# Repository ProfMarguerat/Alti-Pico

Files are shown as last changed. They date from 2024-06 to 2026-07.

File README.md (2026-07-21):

# Alti Pico

Programme pour altimètre à partir d'un Raspberry Pico.  
Le schéma est identique que vous utilisiez un BMP280 ou un BME280 (seul la prise d'hygrométrie diffère pour le bme).  
Il y a un code pour le BMP et un autre pour le BME.  
Il y a également une librairie pour chaque composant.  
Il est possible de télécharger les librairies directement avec Thonny.  

Pour construire cet altimètre, il faut :
- un raspberry Pico
- un lipo Shim pour Pico
- une petite batterie lipo 
- un ecran oled 0,96"
- un capteur BME280
- un buzzer
- un bouton poussoir
- une plaque de prototypage pour braser les différents éléments.

Dans la partie Support_3D, vous retrouverez les fichiers pour fabriquer un support allant dans un tube de 40mm de diamètre interne.

Il y a une version avec la commande d'un servo moteur pour ouvrir une trape juste après l'apogée.

## Dossier du Pico :



## Schéma de câblage :

alti_pico_bb

## Construction :

IMG_0586_resultat
IMG_0587_resultat
IMG_0588_resultat
IMG_0589_resultat
IMG_0591_resultat
IMG_0594_resultat




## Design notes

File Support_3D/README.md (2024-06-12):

Support pour ogive de 40mm de diamètre interne.  

https://github.com/ProfMarguerat/Alti-Pico/assets/171016883/6b52e9af-b229-4efd-b042-83c573405da9

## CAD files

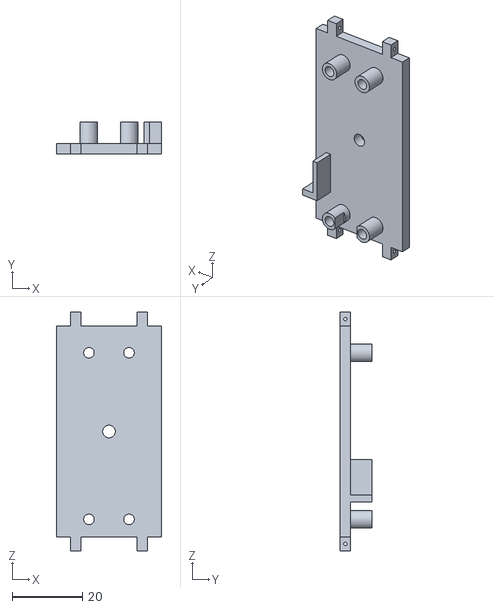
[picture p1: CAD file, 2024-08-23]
Support_3D/Plaque-Support_pico-40_III.STL
30.0 x 9.00 x 68.0

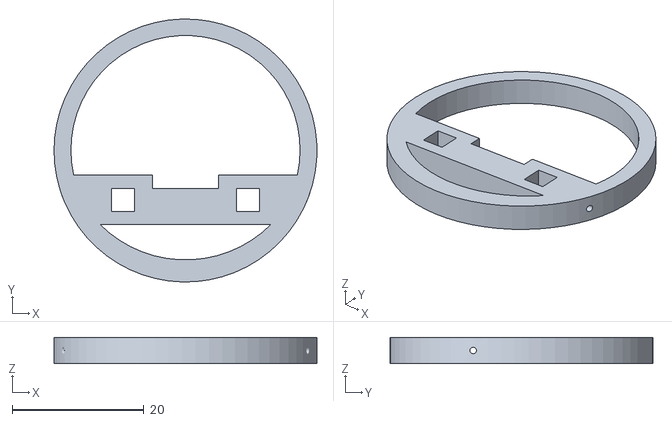
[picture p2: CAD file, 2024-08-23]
Support_3D/Bout_support_pico-40.STL
40.0 x 40.0 x 4.00

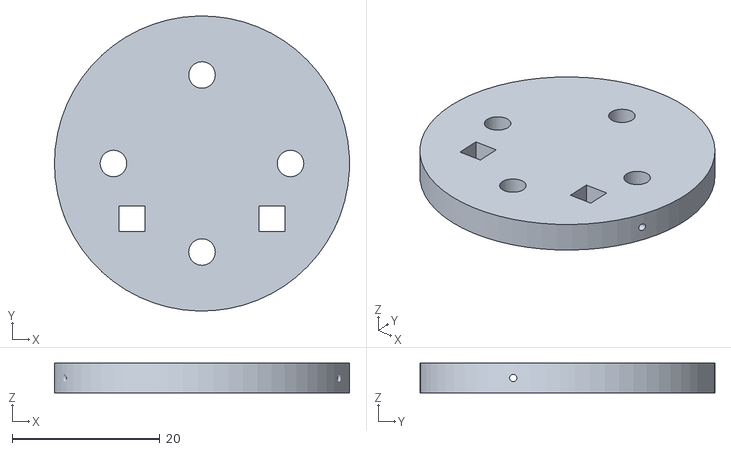
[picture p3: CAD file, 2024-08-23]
Support_3D/Bout-ogive_support_pico-40.STL
40.0 x 40.0 x 4.00

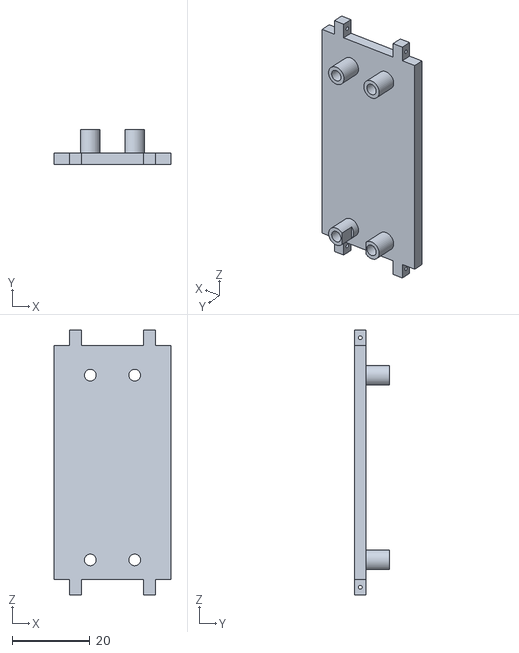
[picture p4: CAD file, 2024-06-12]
Support_3D/Plaque-Support_pico-40_II.STL
30.0 x 9.00 x 68.0

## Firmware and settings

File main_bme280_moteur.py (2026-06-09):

# Programme pour altimètre Pico avec un BME280


# import the required libraries
import bme280
from machine import Pin, I2C, PWM, Timer
import utime, _thread, math
from ssd1306 import SSD1306_I2C
from random import randint
from time import ticks_ms, sleep

led = Pin("LED", Pin.OUT)
led.on()

#Initialisation moteur porte :

servo = machine.PWM(machine.Pin(15))  # signal PWM à la broche GP 15
servo.freq(50) # réglage de la fréquence

servo.duty_u16(4000)    # rapport cyclique 3500/65535
utime.sleep(.5)          # temps d'arrêt


print("creation d'un nouveau fichier")
r = randint (0,1000000000)
fichier =("BME280_Tableau")+(str(r))+(".csv")
print(fichier)#juste pour verif le nom du fichier en debug
tableau_valeur = open(fichier,'w')
tableau_valeur.write('Temperature ; Pression ; Altitude ; Temps')
tableau_valeur.close()

led.off()

sea_level_pressure = 1013.25
cpt=0
boutton = Pin(10, mode=Pin.IN, pull=Pin.PULL_UP)
buzzer = PWM(Pin(16))
buzzer.freq(400)
buzzer.duty_u16(1000)
utime.sleep(0.1)
buzzer.duty_u16(0)


# Caliberation error in pressure
# use it according to your situation
# it helps in calibrating altitude .It is optional, else put ERROR = 0 
ERROR = -3 # hPa 

# declare pins for I2C communication
sclPin = Pin(9) # serial clock pin
sdaPin = Pin(8) # serial data pin

# Initiate I2C 
i2c = I2C(0,              # positional argument - I2C id
                 scl = sclPin,   # named argument - serial clock pin
                 sda = sdaPin,   # named argument - serial data pin
                 freq = 1000000) # named argument - i2c frequency

WIDTH =128 
HEIGHT= 32
oled = SSD1306_I2C(WIDTH,HEIGHT,i2c)
import framebuf

TH = bytearray(b'\x00\x00\x00\x00\x00\x00\x00\x00\x10\x00\x00\x00\x10\x00\x00\x00\x00\x00\x00\x00\x00\x00\x00\x00\x00\x00\x00\x00\x10\x00\x00\x00\x00\x01\x00\x00\x00\x01\x00\x00\x00\x00\x00\x00\x00\x00\x00\x00\x00\x00\x00\x00\x00\x00\x00\x00\x00\x00\x08\x00\x04\x00\x08\x00\x00\x00\x00\x00\x00\x00\x00\x00\x00\x00\x00\x00\x00\x00\x00\x00\x00\x00\x08\x10\x00\x00\x08\x10\x00\x00\x00 \x00\x00\x00 \x00\x00\x00\x02\x00\x00\x00\x02\x00\x01\x00\x00\x00\t\x00\x00B\x02\x0f\xe0@\x00\x00\x00\x80\x00\x7f\xf8\x00\x00\x00\x00\x00\x07\xff\xfc\x80\x00\x00\x00\x00\x0f\xff\xfc\x00\x00\x00\x00\x00/\xff\xfe\x04\x00\n\x00\x00\x03\xff\xfe\x00\x00\x00\x00\x02\x03\xff\xff\x00\x02\x00\x00\x00\x00\x7f\xff?\xfc\x00P\x00\x00?\xff\xff\xff\x80\x00\x00\x00\x0f\xff\xff\xff\xf0\x08\x00\xbe\x07\xff\xff\xff\xfc\x10\x01\xff\x8f\xff\xff\xff\xfc\x10\x03\xff\xdf\xff\xff\xff\xfd\x80\x07\xe0\xdf\xff\xff\xff\xfd\xc0\x0f\x86_\xff\xff\xe7\xfd\xe0\x1f\x9e_\xff\xff\xc3\xfd\xf8?\x1e_\xff\xff\x81\xfd\xf8??_\xff\xff\x81\xfd\xfc?>_\xff\xff\x91\xfd\xfc?\x1e_\xff\xff\x81\xfd\xf8\x1f\x9e_\xff\xff\xc3\xfd\xf0\x0f\xc6_\xff\xff\xe7\xfd\xe4\x07\xe0\xdf\xff\xff\xff\xfd\xc0\x03\xff\xdf\xff\xff\xff\xff\x00\x01\xff\x8f\xff\xff\xff\xfc\x00\x00>\x07\xff\xff\xff\xfc\x00\x00\x04\x0f\xff\xff\xff\xf2\x00\x00\x00?\xff\xff\xff\x80\x00\x00\x00\x7f\xff?\xfc\x00\x00\x01\x01\xff\xff\x00\x00\x00\x00\x00\x03\xff\xfe\x00\x00\x00\x00@\x0f\xff\xfe\x00\x00\x00\x00\x04\x0f\xff\xfc\x04\x08@\x00\x00C\xff\xfc\x00\x00\x00\x00\x00@\x7f\xf9\x00\x00\x00\x00\x00\x80\x0f\xe0\x01\x00\x00\x00\x02\x10\x80\x00\x08\x00\x04 \x08\x02\x81\t\x00\x02\x00\x00\x00\x00\x00\x00\x00\x00\x00\x00\x08\x00\x00\xa0\x02\x00\x00\x00\x00\x10\x00\x80\x08@\x00\x00\x00\x00\x00\x00\x00\x00\x00\x00\x00\x00\x00\x00\x00\x00\x04\x00\x00\x00\x00\x00\x00\x00\x10\x00\x00\x01\x00\x02\x00\x00\x00\x00\x00\x00\x00\x00\x00\x00\x00\x00\x00\x00\x00 @\x10\x00\x00\x10\x80\x08\x10\x00\x00\x00P\x00\x00\x00\x00\x00\x00\x00\x00\x00\x00\x00\x00\x00\x00\x80\x00')

fb = framebuf.FrameBuffer(TH,128,32, framebuf.MONO_HLSB)
oled.fill(0)
oled.blit(fb,60,0)
oled.show()
utime.sleep(1)

texte_complet = fichier
longueur = len(texte_complet)
for n in range(0,longueur - 1):
    oled.fill(0)    
    texte = texte_complet[n:16 + n]
    oled.text(texte,0,15)
        #lignes horizontales
    oled.hline(0,7,127,1)
    oled.hline(0,30,127,1)
    oled.show()
    utime.sleep(0.1)

texte_complet = "Appuie long RAZ      "
longueur = len(texte_complet)
for n in range(0,longueur - 1):
    oled.fill(0)    
    texte = texte_complet[n:16 + n]
    oled.text(texte,0,15)
        #lignes horizontales
    oled.hline(0,7,127,1)
    oled.hline(0,30,127,1)
    oled.show()
    utime.sleep(0.1)

#oled.fill(0)
oled.text("Bon vol !", 30, 16)
oled.show()
utime.sleep(0.5)

bme = bme280.BME280(i2c=i2c)

#Attente appuie sur bouton pour bloquer la porte
while boutton.value()== 1 :
    utime.sleep(0.1)
    #print ("Attente appui")
    oled.fill(0)
    oled.text("Attente appui ", 0, 16)
    oled.show()
        
#print ("Blocage porte")
oled.fill(0)
oled.text("Blocage porte", 0, 16)
oled.show()
servo.duty_u16(7000)    # rapport cyclique 3500/65535
utime.sleep(0.4)
buzzer.freq(400)
buzzer.duty_u16(1000)
utime.sleep(0.1)
buzzer.duty_u16(0)

while boutton.value()== 1 :
    utime.sleep(0.1)
            #print ("Attente appui")
    oled.fill(0)
    oled.text("Attente appui ", 0, 8)
    oled.text("pour debut acquisition ", 0, 16)
    oled.show()

# Function for calculation altitude from pressure and temperature values
# because altitude() method is not present in the Library

def altitude_HYP(hPa , temperature):
    # Hypsometric Equation (Max Altitude < 11 Km above sea level)
    temperature = temperature
    local_pressure = hPa
    sea_level_pressure = 1013.25 # hPa      
    pressure_ratio = sea_level_pressure/local_pressure # sea level pressure = 1013.25 hPa
    h = (((pressure_ratio**(1/5.257)) - 1) * temperature ) / 0.0065
    return h


# altitude from international barometric formula, given in BMP 180 datasheet
def altitude_IBF(pressure):
    local_pressure = pressure    # Unit : hPa
    sea_level_pressure = 1013.25 # Unit : hPa
    #sea_level_pressure = 1009 # QNH Unit : hPa
    
    pressure_ratio = local_pressure / sea_level_pressure
    
    altitude = 44330*(1-(pressure_ratio**(1/5.255)))
    return altitude

def affichage(afficheur) :
    if afficheur ==0 :
        oled.text("Alt_ref :", 0, 0)
        oled.text(str(round(altitude0,2)), 70, 0)
        oled.text("Alt:", 0, 8)
        oled.text(str(round(altitude,2)), 70, 8)
        oled.text("Alt_M:", 0, 16)
        oled.text(str(round(altitude_max,2)), 70, 16)
        oled.text("Tps (s):",00,24)
        oled.text(str(elapsed_time/1000),70,24)
        oled.text(str(r), 0, 48)
        oled.show()
        led.off()

    if afficheur ==1:
        oled.text("Alt_ref :", 0, 0)
        oled.text(str(round(altitude0,2)), 70, 0)
        oled.text("Haut:", 0, 8)
        oled.text(str(round(altitude-altitude0,2)), 70, 8)
        oled.text("Haut_M:", 0, 16)
        oled.text(str(round(altitude_max-altitude0,2)), 70, 16)
        oled.text("Tps (s):",00,24)
        oled.text(str(elapsed_time/1000),70,24)
        oled.show()
        led.off()

    if afficheur ==2:
        oled.text("Temperature:", 0, 0)
        oled.text(str(round(temperature_c,1)), 0, 8)
        oled.text("Pression actuelle :", 0, 16)
        oled.text(str(round(pressure_hPa,2)), 0, 24)
        oled.show()
        led.off()

    if afficheur == 3:
        oled.text("Num fichier:", 0, 0)
        oled.text(str(r), 0, 8)
        oled.show()
        led.off()
        

 
t=bme.values[0]
tt=float(t[:len(t) - 1])
temperature_c = float(tt) # degree celcius
    
    # convert celcius to kelvin
temperature_k = temperature_c + 273.15
    
    # accquire pressure value
pressure_hPa = float(bme.values[1][:len(bme.values[1]) - 3])  # hectopascal
    
    # accquire altitude values from HYPSOMETRIC formula
h = altitude_HYP(pressure_hPa, temperature_k)
    
    # accquire altitude values from International Barometric Formula
altitude0 = altitude_IBF(pressure_hPa)

oled.fill(0)
oled.text("Alt_0:", 0, 16)
oled.text(str(round(altitude0,2)), 70, 16)
oled.show()
utime.sleep(1)

#_thread.start_new_thread(thread_anim, ()) 

tableau_valeur = open(fichier,'a') #ouverture
start_time = 0
start = 0
stop = 0
elapsed_time = 0
afficheur = 0
apogee = 0
atterrissage = 0 
alt2=altitude0+8
altitude_max = -999
hauteur=0
porte, elapsed_time_p, start_p  = 1,0,0 #Porte = 1 : porte férmée
utime.sleep (0.1)

while True:
    #elapsed_time = ticks_ms() - start_time  # Calcule le temps écoulé
    #print(f"Temps écoulé: {elapsed_time} millisecondes")
    oled.fill(0)
#    rled.on()
    # accquire temperature value in celcius
    t=bme.values[0]
    tt=float(t[:len(t) - 1])
    temperature_c = float(tt) # degree celcius
    
    # convert celcius to kelvin
    temperature_k = temperature_c + 273.15
    
    # accquire pressure value
    pressure_hPa = float(bme.values[1][:len(bme.values[1]) - 3])  # hectopascal
    
    # accquire altitude values from HYPSOMETRIC formula
    h = altitude_HYP(pressure_hPa, temperature_k)
    
    # accquire altitude values from International Barometric Formula
    altitude = altitude_IBF(pressure_hPa)
    
    #print("Temperature : ",temperature_c," Degree Celcius")
    #print("Pressure : ",pressure," Pascal (Pa)")
    #print("Pressure : ",pressure_hPa," hectopascal (hPa) or millibar (mb)")
    #print("Altitude (Hypsometric Formula) : ", h ," meter")
    #print("Altitude (International Barometric Formula) : ", altitude ," meter")

    temp =str(temperature_c)
    press = str(pressure_hPa)
    alt=str(altitude)
    pt = str(elapsed_time/1000)
    tableau_valeur = open(fichier,'a')
    tableau_valeur.write("\n")
    tableau_valeur.write(temp+";"+press+";"+alt+";"+pt)
    tableau_valeur.close()
    led.on()
    
    if boutton.value()==0:
        utime.sleep(0.5)
        if boutton.value()==0:
            altitude_max=-999
            altitude0 = altitude_IBF(pressure_hPa)
            alt2=altitude0+8
            elapsed_time = 0
            apogee = 0
            start = 0
            atterrissage = 0
            porte, elapsed_time_p, start_p  = 0, 0, 0
            oled.fill(0)
            led.on()
            oled.text("RAZ Altitude max", 0, 16)
            oled.show()
            utime.sleep(0.8)
            led.off()
            oled.fill(0)
            servo.duty_u16(4000)    # rapport cyclique 3500/65535 ouverture de la porte
            utime.sleep(0.2)
            porte = 0
            #Attente appuie sur bouton pour bloquer la porte
            while boutton.value()== 1 :
                utime.sleep(0.1)
            #print ("Attente appui")
                oled.fill(0)
                oled.text("Attente appui ", 0, 16)
                oled.show()
        
            #print ("Blocage porte")
            oled.fill(0)
            oled.text("Blocage porte", 0, 16)
            oled.show()
            porte = 1
            servo.duty_u16(7000)    # rapport cyclique 3500/65535
            utime.sleep(0.4)
            buzzer.freq(400)
            buzzer.duty_u16(1000)
            utime.sleep(0.05)
            buzzer.duty_u16(0)
            while boutton.value()== 1 :
                utime.sleep(0.1)
                #print ("Attente appui")
                oled.fill(0)
                oled.text("Attente appui ", 0, 8)
                oled.text("pour debut acquisition ", 0, 16)
                oled.show()

        
        
        else :
            afficheur += 1
            if afficheur == 4 :
                afficheur = 0
    
    
    if altitude>altitude_max : 
        altitude_max=altitude
    
    #alt=altitude0+2
    #print (alt2)
    # Démarrage chrono lorsque l'altitude dépasse celle de départ plus 8m pour pallier aux dérives de pression :
    if altitude > alt2 and start == 0:
        #print ("c'est parti !")
        tableau_valeur = open(fichier,'a')
        tableau_valeur.write("\n")
        tableau_valeur.write("Départ")
        tableau_valeur.close()
        start = 1
        start_time = ticks_ms()
        start_p = 1
        
    
    # Défilement du chrono à condition qu'il soit parti, la condition sur start permet de remettre le chrono à zero :
    if start == 1 :
        elapsed_time = ticks_ms() - start_time  
    
    # Défilement du chrono à condition qu'il soit parti, sans arrêt, contrairement à start qui s'arrête quand la fusée a atterrie :
    if start_p == 1 :
        elapsed_time_p = ticks_ms() - start_time
        #print (elapsed_time, elapsed_time_p/1000)
        
    # Ouverture de la porte après 5s de vol. La variable porte permet d'éviter la redondance de l'ouverture de la porte à chaque rotation du porgramme:
    #if (elapsed_time_p/1000) > 5 and porte == 1 :
    #    servo.duty_u16(4000)    # rapport cyclique 3500/65535
    #    utime.sleep(.1)
    #    porte = 0

    # Détection de l'apogée (-1m pour éviter que ça se déclenche avec la dérive) :
    if altitude < altitude_max-1 and start == 1 and apogee == 0 :
        tableau_valeur = open(fichier,'a')
        tableau_valeur.write("\n")
        tableau_valeur.write("Apogée !")
        tableau_valeur.close()
        apogee = 1
        buzzer.freq(400)
        buzzer.duty_u16(1000)
        utime.sleep(0.05)
        buzzer.duty_u16(0)
    
    # Ouverture de la porte à altitude 20m :
    hauteur=altitude-altitude0
    if hauteur < 20 and apogee == 1 and porte == 1:
        tableau_valeur = open(fichier,'a')
        tableau_valeur.write("\n")
        tableau_valeur.write("Ouverture porte")
        tableau_valeur.close()
        servo.duty_u16(4000)    # rapport cyclique 3500/65535
        utime.sleep(.5)          # temps d'arrêt
        porte = 0
    
    # Arrêt du chrono et remise à zero suite à un atterrissage :
    if altitude <= altitude0 and start == 1 :
        tableau_valeur = open(fichier,'a')
        tableau_valeur.write("\n")
        tableau_valeur.write("Atterrissage")
        tableau_valeur.close()
        start = 0
        atterrissage = 1
        #Pour éviter que ça se remette à zéro intempestivement :
        alt2 = alt2+10
    
    #Buzzer pour retrouver la fusée au sol  
    if atterrissage == 1 :
        buzzer.freq(400)
        buzzer.duty_u16(1000)
        utime.sleep(0.05)
        buzzer.duty_u16(0)
    
    #print (altitude)
    #print (hauteur)
    
    affichage(afficheur)  
    
   
